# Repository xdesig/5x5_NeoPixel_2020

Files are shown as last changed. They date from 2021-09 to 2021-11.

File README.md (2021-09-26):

# Pantalla 25 (5x5) Neopixel 2020



## Aplicación
Con EchidnaBlack


## Serigrafía
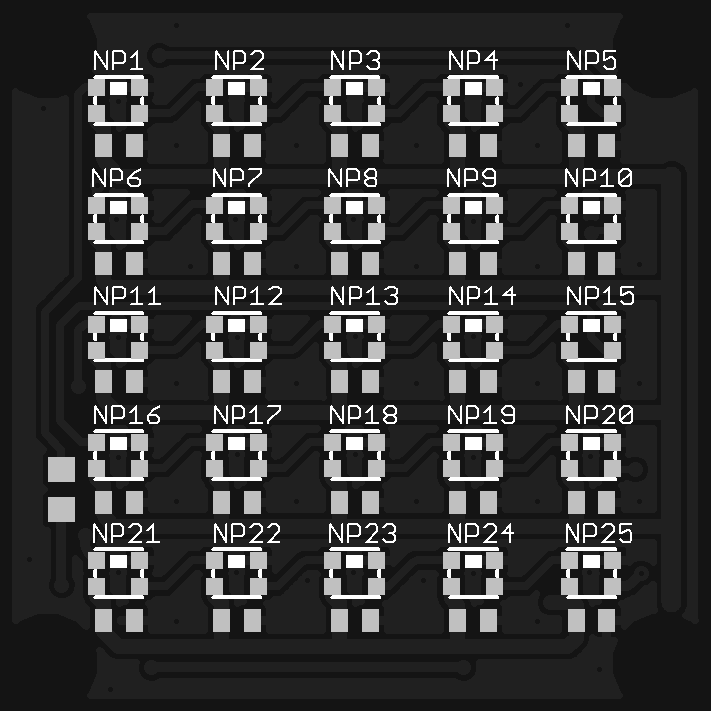
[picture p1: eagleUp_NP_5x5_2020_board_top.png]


## Esquema
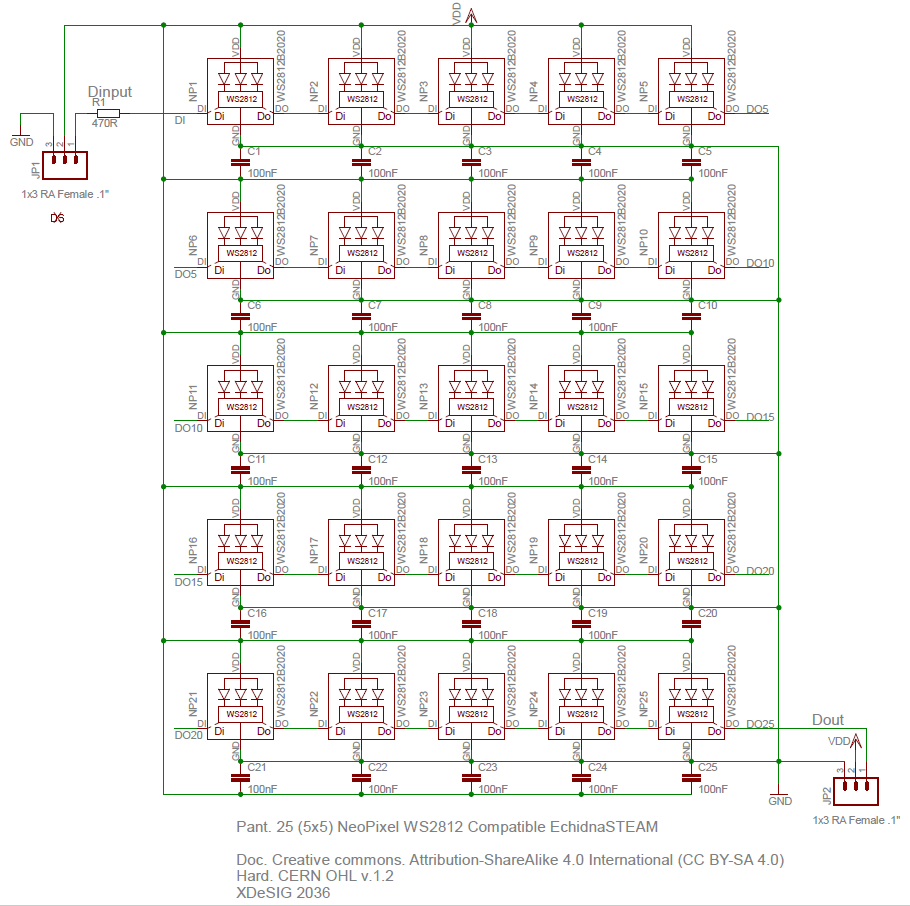
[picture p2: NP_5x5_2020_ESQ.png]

Os capacitores son opcionais

## Licencia
Doc. Creative commons. Attribution-ShareAlike 4.0 International (CC BY-SA 4.0) Hard. CERN OHL v.1.2XDeSIG 2036

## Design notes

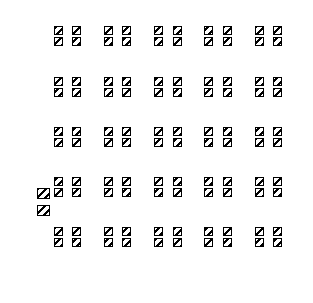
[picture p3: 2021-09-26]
NP_5x5_2020_Stenc_XC.png

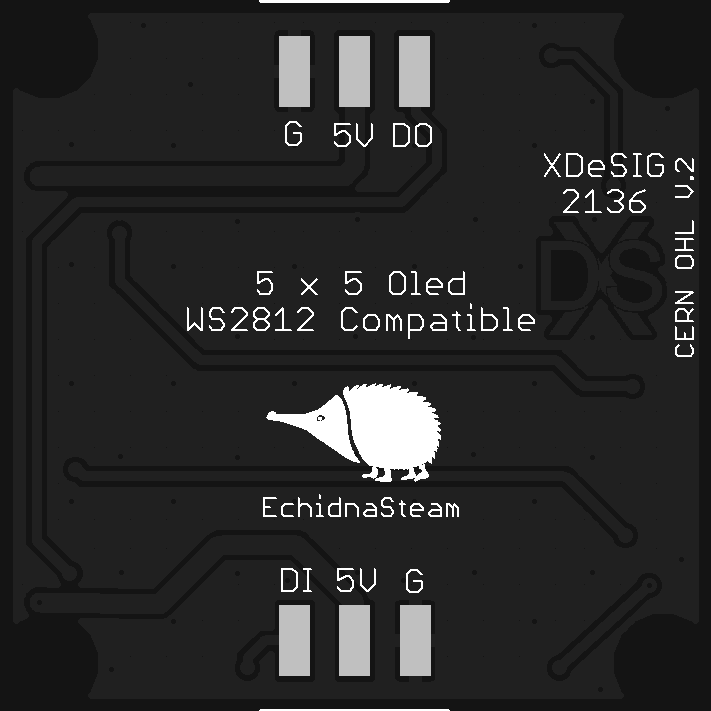
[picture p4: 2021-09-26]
eagleUp_NP_5x5_2020_board_bottom.png

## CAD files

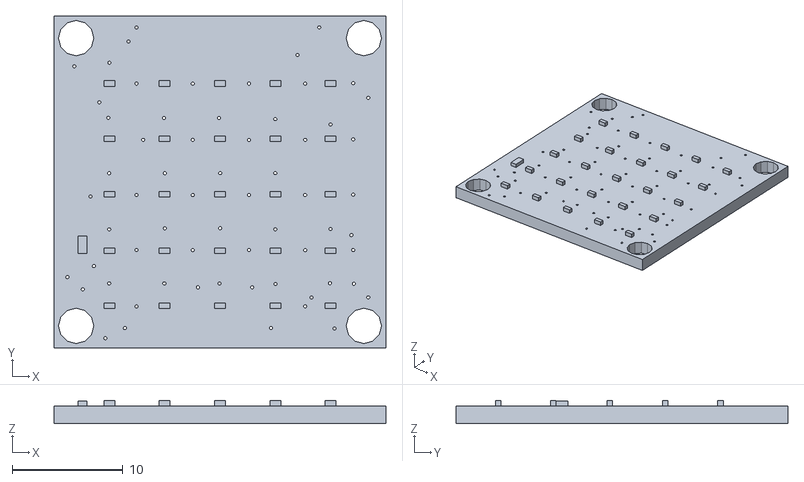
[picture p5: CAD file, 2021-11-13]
3D/NP_5x5_2020.stl
30.0 x 30.0 x 2.10

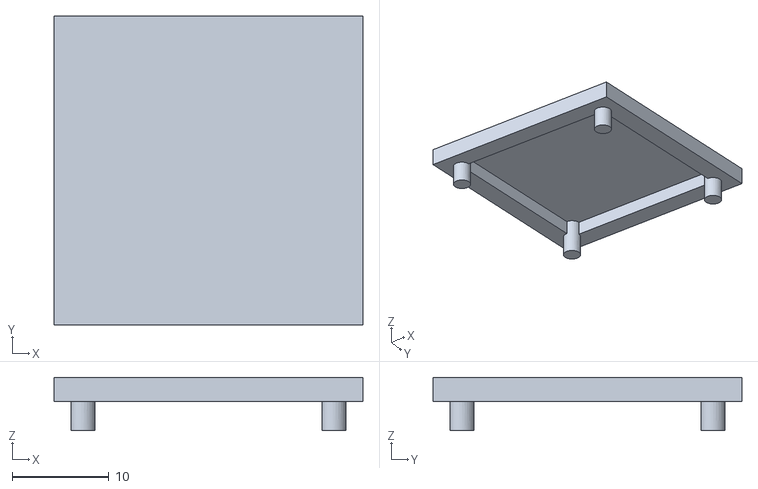
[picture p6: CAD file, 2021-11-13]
3D/NP_5x5_2020_cubre.stl
32.0 x 32.0 x 5.50

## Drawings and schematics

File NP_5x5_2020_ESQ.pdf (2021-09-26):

## Dinput

# XDeSIG 2036 WS²⁸¹²B²⁰²⁰

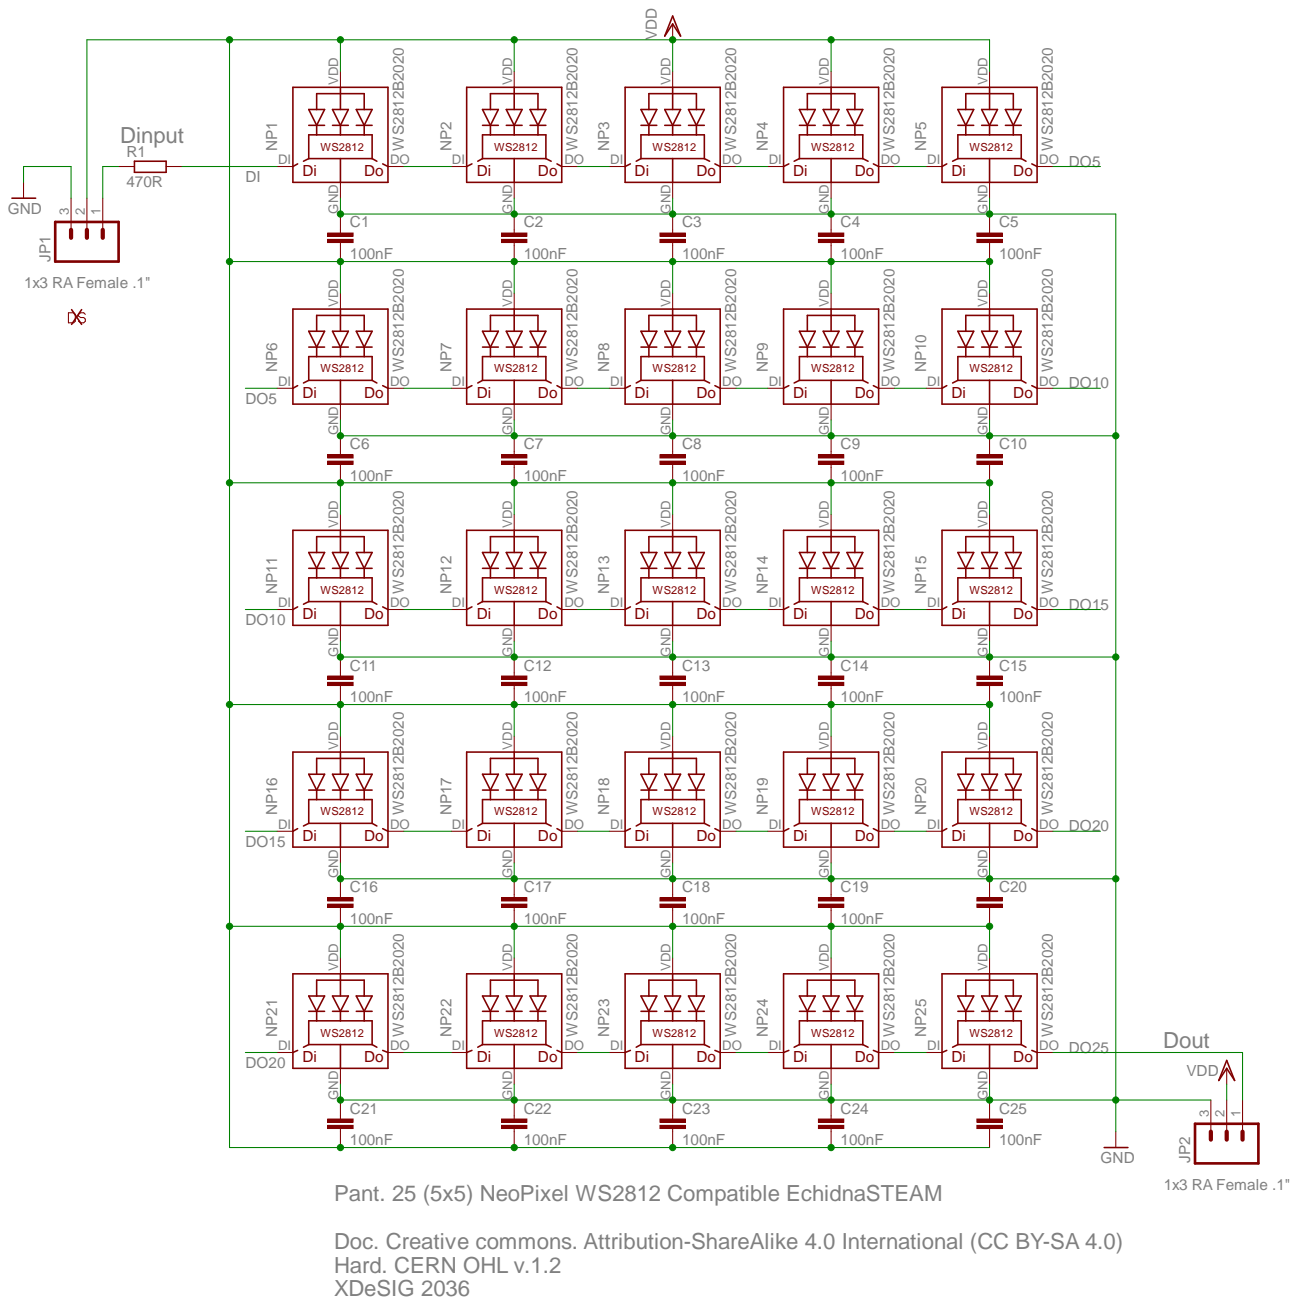
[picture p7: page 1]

Pant. 25 (5x5) NeoPixel WS2812 Compatible EchidnaSTEAM

Doc. Creative commons. Attribution-ShareAlike 4.0 International (CC BY-SA 4.0)
Hard. CERN OHL v.1.2

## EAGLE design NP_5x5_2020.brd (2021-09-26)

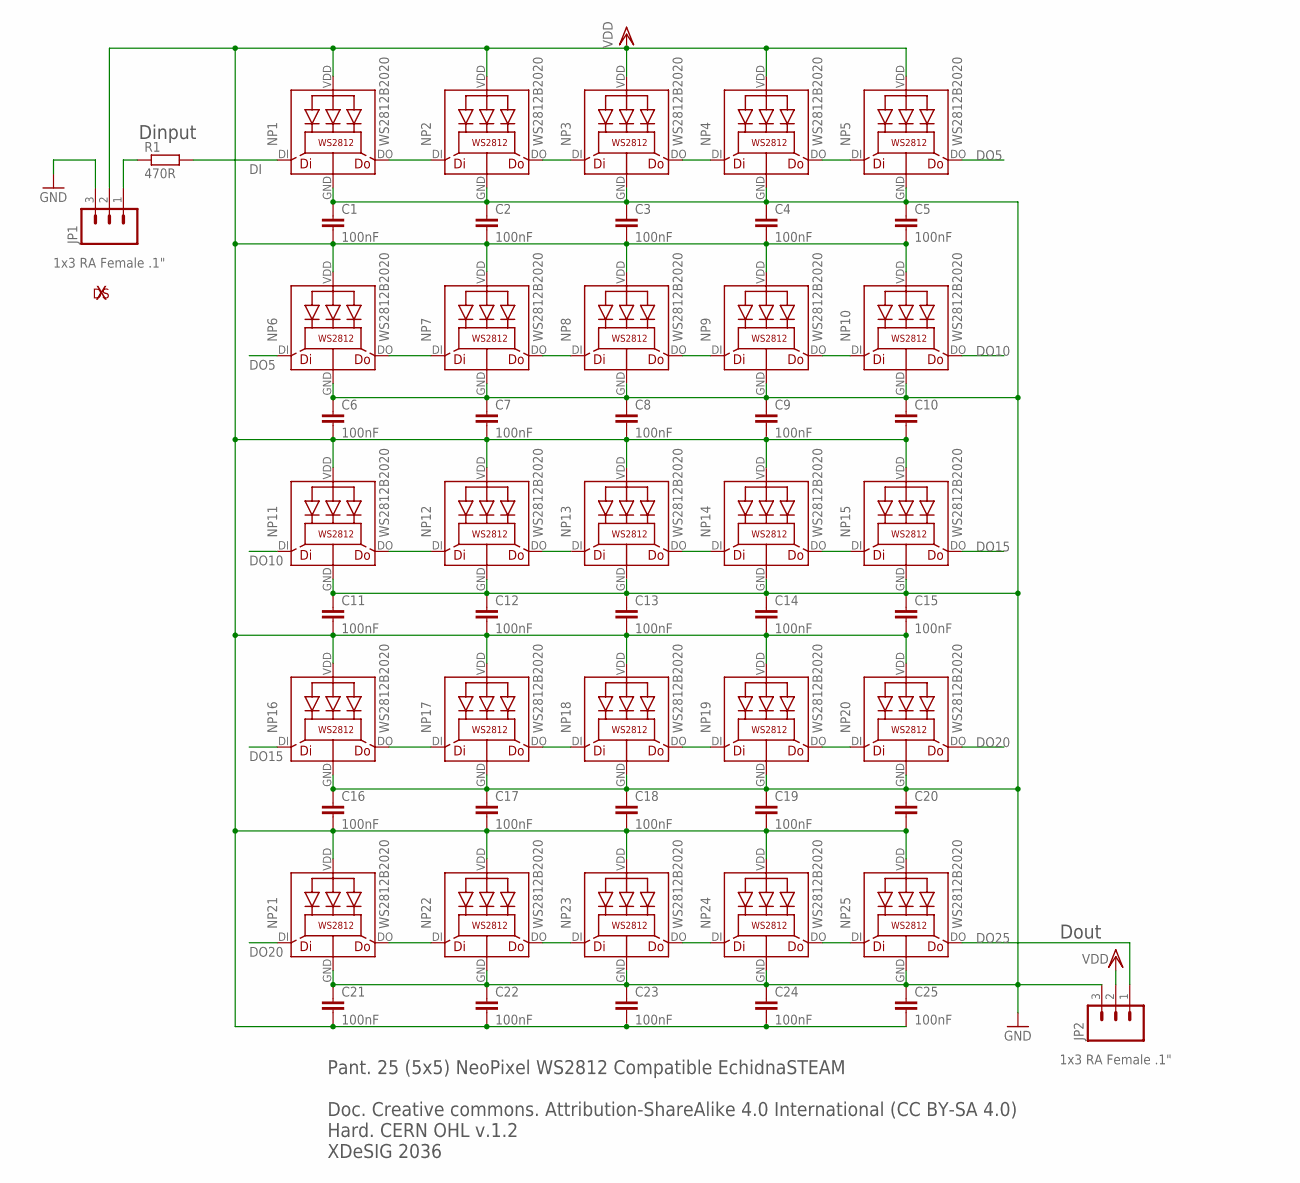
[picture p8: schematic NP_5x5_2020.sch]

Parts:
C1, C2, C3, C4, C5, C6, C7, C8, C9, C11, C12, C13, C14, C15, C16, C17, C18, C19, C21, C22, C23, C24, C25: 100nF; C0402
C10, C20: C-EUC0402; C0402
JP1, JP2: 1x3 RA Female .1"; 1X03_SMD_RA_FEMALE
NP1, NP2, NP3, NP4, NP5, NP6, NP7, NP8, NP9, NP10, NP11, NP12, NP13, NP14, NP15, NP16, NP17, NP18, NP19, NP20, NP21, NP22, NP23, NP24, NP25: WS2812B2020; 2020
R1: 470R; R0603
U$1: XDESIG_XDESIG5MM; XDESIG_XDESIG_CU

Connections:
DI: NP1.DI, R1.2
DO5: NP5.DO, NP6.DI
DO10: NP10.DO, NP11.DI
DO15: NP15.DO, NP16.DI
DO20: NP20.DO, NP21.DI
DO25: JP2.1, NP25.DO
GND: C1.1, C2.1, C3.1, C4.1, C5.1, C6.1, C7.1, C8.1, C9.1, C10.1, C11.1, C12.1, C13.1, C14.1, C15.1, C16.1, C17.1, C18.1, C19.1, C20.1, C21.1, C22.1, C23.1, C24.1, C25.1, JP1.3, JP2.3, NP1.GND, NP2.GND, NP3.GND, NP4.GND, NP5.GND, NP6.GND, NP7.GND, NP8.GND, NP9.GND, NP10.GND, NP11.GND, NP12.GND, NP13.GND, NP14.GND, NP15.GND, NP16.GND, NP17.GND, NP18.GND, NP19.GND, NP20.GND, NP21.GND, NP22.GND, NP23.GND, NP24.GND, NP25.GND
unnamed: NP1.DO, NP2.DI
unnamed: NP2.DO, NP3.DI
unnamed: NP3.DO, NP4.DI
unnamed: NP4.DO, NP5.DI
unnamed: NP22.DO, NP23.DI
unnamed: NP23.DO, NP24.DI
unnamed: NP6.DO, NP7.DI
unnamed: NP7.DO, NP8.DI
unnamed: NP8.DO, NP9.DI
unnamed: NP9.DO, NP10.DI
unnamed: NP11.DO, NP12.DI
unnamed: NP12.DO, NP13.DI
unnamed: NP13.DO, NP14.DI
unnamed: NP14.DO, NP15.DI
unnamed: NP16.DO, NP17.DI
unnamed: NP17.DO, NP18.DI
unnamed: NP18.DO, NP19.DI
unnamed: NP19.DO, NP20.DI
unnamed: NP21.DO, NP22.DI
unnamed: NP24.DO, NP25.DI
unnamed: JP1.1, R1.1
VDD: C1.2, C2.2, C3.2, C4.2, C5.2, C6.2, C7.2, C8.2, C9.2, C10.2, C11.2, C12.2, C13.2, C14.2, C15.2, C16.2, C17.2, C18.2, C19.2, C20.2, C21.2, C22.2, C23.2, C24.2, C25.2, JP1.2, JP2.2, NP1.VDD (LEDVDD), NP2.VDD (LEDVDD), NP3.VDD (LEDVDD), NP4.VDD (LEDVDD), NP5.VDD (LEDVDD), NP6.VDD (LEDVDD), NP7.VDD (LEDVDD), NP8.VDD (LEDVDD), NP9.VDD (LEDVDD), NP10.VDD (LEDVDD), NP11.VDD (LEDVDD), NP12.VDD (LEDVDD), NP13.VDD (LEDVDD), NP14.VDD (LEDVDD), NP15.VDD (LEDVDD), NP16.VDD (LEDVDD), NP17.VDD (LEDVDD), NP18.VDD (LEDVDD), NP19.VDD (LEDVDD), NP20.VDD (LEDVDD), NP21.VDD (LEDVDD), NP22.VDD (LEDVDD), NP23.VDD (LEDVDD), NP24.VDD (LEDVDD), NP25.VDD (LEDVDD)

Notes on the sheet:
Dout
Dinput
Pant. 25 (5x5) NeoPixel WS2812 Compatible EchidnaSTEAM Doc. Creative commons. Attribution-ShareAlike 4.0 International (CC BY-SA 4.0) Hard. CERN OHL v.1.2 XDeSIG 2036

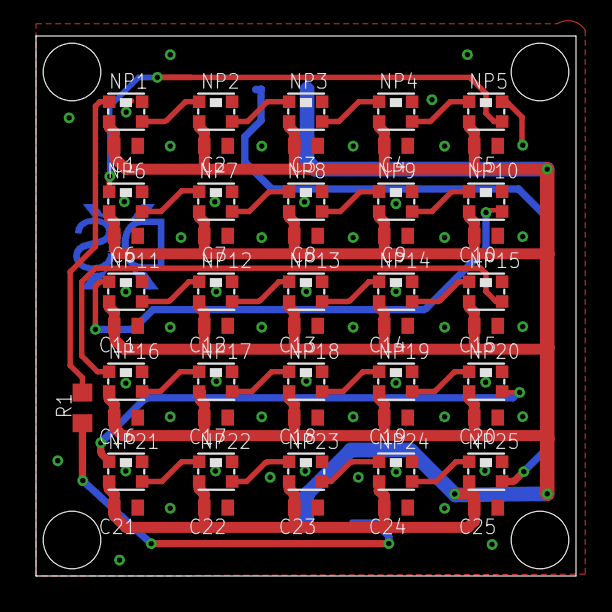
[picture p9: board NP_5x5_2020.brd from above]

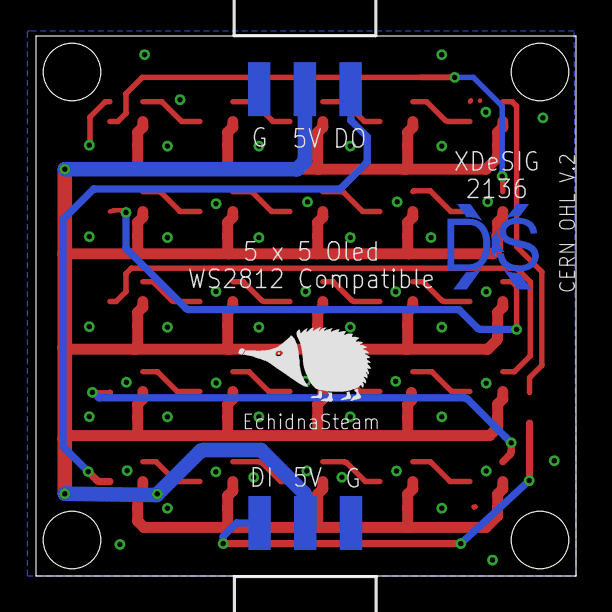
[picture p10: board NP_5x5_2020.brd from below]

Board: 2 copper layers, 30.0 x 30.0 mm, 55 parts (4 on the bottom side), 29 nets.

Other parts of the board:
U$3: ECHIDNA_P

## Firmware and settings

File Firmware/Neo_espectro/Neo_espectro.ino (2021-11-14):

/*
    Visualizador de espectro de audio de cinco bandas
    Usando a pantalla de 25 Neopixeles "https://github.com/xdesig/5x5_NeoPixel_2020"
    Transformada rapida de Fourier (FFT). Autor: Dimitrios P. Bouras, mantenida por Enrique Condes
    Pulsando SR aumentamos a amplificacion, Sl baixamos a amplificacion
    O Led vermello indica maxima amplificación o laranxa media e o verde minima. 
    XDeSIG 2021
*/

#include <Adafruit_NeoPixel.h>
#define PIN_NEO A4
#define NUM_LEDS 25
Adafruit_NeoPixel pixels = Adafruit_NeoPixel(NUM_LEDS, PIN_NEO, NEO_GRB + NEO_KHZ800);


#include <fix_fft.h>          // biblioteca para implementar FFT
char re[128], im[128];        // Matrices de muestras / resultados de la FFT
byte i;                       // indice para almacenar as mostras
int dat;                      // variable da amplitude da frecuencia

int F[5] = {2, 3, 6, 9, 15}; // Frecuencias a mostrar en pantalla *73,8Hz

#define MIC A7
// Entrada de Audio (Microfono)

#define SR 2                  // Pulsador para subir a amplificacion
#define SL 3                  // Pulsador para bajar a amplificacion
#define Red 13                // Led vermello (Amplificación maxima)
#define Orn 12                // Led laranxa (Amplificación media)
#define Gre 11                // Led verde (Amplificación minima)

int amp = 25;                 // Valor inicial de amplificacion


int y;                        // Variable de resultados (eixo Y) mapeados para mostrar na pantalla
int x;                        // variable para recorer o eixo x
int A;                        // Amplitude en leds
int pix;                      // Variable de pixel a mostrar (pix = x + y*5)

int R;                        // Variable da cor vermella
int G;                        // Variable da cor verde
int B;                        // Variable da cor azul



void setup() {
  analogReference(INTERNAL);    // Axustamos a referencia do conversos analoxico/dixital a 1.1Volts
  pinMode(SR, INPUT);           // Definimos o rol de cada pin
  pinMode(SL, INPUT);
  pinMode (Red, OUTPUT);
  pinMode (Orn, OUTPUT);
  pinMode (Gre, OUTPUT);

  pixels.begin();              // Inicializamos os neoPixeles
}

void loop() {

  // *** Comprobamos si se pulsou SR para amplificar ou SR par atenuar
  while (digitalRead (SR)) {
    amp = amp + 1;
    if ( amp >= 50) {
      amp = 50;
      digitalWrite (Red, 1);
      digitalWrite (Orn, 0);
      digitalWrite (Gre, 0);
    }
    delay(100);
  }
  while (digitalRead (SL) ) {
    amp = amp - 1;
    if ( amp <= 1) {
      amp = 1;
      digitalWrite (Red, 0);
      digitalWrite (Orn, 0);
      digitalWrite (Gre, 1);
    }
    delay(100);
  }
  // *** Comprobamos si o valor de amplificacion e medio e acendemos o led laranxa
  if (amp > 20 and amp < 30) {
    digitalWrite (Red, 0);
    digitalWrite (Orn, 1);
    digitalWrite (Gre, 0);
  }



  //*** lectura de audio e conversion a amplitude por frecuencia.

  for (i = 0; i < 128; i++) {                     // Tomamos 128 mostras da entrada analoxica (micro)
    int sample = amp * (analogRead(MIC));
    re[i] = sample / 4 - 128;                     // Escalamos a variable para que se axuste a un caracter de -128 a 127
    im[i] = 0;                                    // Neste momento non temos valores imaxinarios e poñemos todos a cero
  }
  fix_fft(re, im, 7, 0);                          // Enviamos as mostras para a conversión FFT, devolvendo os resultados reais/imaxinarios nas mesmas matrices


  for (x = 0; x < 5; x++) {                       // Recorremos o eixo x da pantalla

    dat = sqrt(re[F[x]] * re[F[x]] + im[F[x]] * im[F[x]]);     // A magnitude da frecuencia é a raíz cadrada da suma dos cadrados das partes real e imaxinaria dos vectores
    // Solo recuperamos os valores das frecuencias elixidas F[x]

    A = map(dat, 0, 25, 4, 0);                                 // Mapeamos os valores de amplitude de cada frecunencia os pixeles verticais

    for (y = 5; y >= A  ; y--) {                               // Comprobamos cantos pixeles verticais acendemos

      pix = x + y * 5;                                         // Pasamos  as coordenadas X e Y a linea de pixeles

      if (y == 0) {                                            // Axustamos a cor a cada liña
        R = 32;
        G = 0;
        B = 0;
      }
      if (y == 1) {
        R = 16;
        G = 8;
        B = 4;
      }
      if (y == 2) {
        R = 16;
        G = 8;
        B = 16;
      }

      if (y == 3) {
        R = 4;
        G = 0;
        B = 16;
      }
      if (y == 4) {
        R = 0;
        G = 2;
        B = 2;
      }
      pixels.setPixelColor(pix, pixels.Color(R, G, B));           // Acendemos cada pixel ca sua cor
    }
    for (int y = 0; y < A  ; y++) {                               // Comprobamos que pixeles apagar
      pix = x + y * 5 ;
      pixels.setPixelColor(pix, pixels.Color(0, 0, 0));           // Apagamos cada pixel selecionado
    }
    pixels.show();                                                // Enviamos os datos a pantalla de NeoPixeles
  }
}

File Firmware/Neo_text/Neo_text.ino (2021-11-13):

#include <Adafruit_NeoPixel.h>
#ifdef __AVR__
#include <avr/power.h>
#endif
#define PIN A4
#define NUM_LEDS 25

boolean E[25] = {0, 1, 1, 1, 1,  0, 1, 0, 0, 0,  0, 1, 1, 1, 0,  0, 1, 0, 0, 0,  0, 1, 1, 1, 1};
boolean C[25] = {0, 0, 1, 1, 1,  0, 1, 0, 0, 0,  0, 1, 0, 0, 0,  0, 1, 0, 0, 0,  0, 0, 1, 1, 1};
boolean H[25] = {0, 1, 0, 0, 1,  0, 1, 0, 0, 1,  0, 1, 1, 1, 1,  0, 1, 0, 0, 1,  0, 1, 0, 0, 1};
boolean I[25] = {0, 1, 1, 1, 0,  0, 0, 1, 0, 0,  0, 0, 1, 0, 0,  0, 0, 1, 0, 0,  0, 1, 1, 1, 0};
boolean D[25] = {0, 1, 1, 0, 0,  0, 1, 0, 1, 0,  0, 1, 0, 0, 1,  0, 1, 0, 1, 0,  0, 1, 1, 0, 0};
boolean N[25] = {0, 1, 0, 0, 1,  0, 1, 1, 0, 1,  0, 1, 0, 1, 1,  0, 1, 0, 0, 1,  0, 1, 0, 0, 1};
boolean A[25] = {0, 0, 1, 0, 0,  0, 1, 0, 1, 0,  0, 1, 0, 0, 1,  0, 1, 1, 1, 1,  0, 1, 0, 0, 1};
int wait = 200;
int ret1 = 100;
int R;
int G;
int B;
int i = 0;
Adafruit_NeoPixel pixels = Adafruit_NeoPixel(NUM_LEDS, PIN, NEO_GRB + NEO_KHZ800);

void setup() {
  for (int j = 0; j < 10; j++) {
    pixels.begin();

    for (i = 0; i < 25; i++) {
      R = random(0, 32); G = random(0, 32); B = random(0, 32);
      pixels.setPixelColor(i, pixels.Color(R, G, B));
      pixels.show();
      delay(ret1);
    }
  }
  
  for (i = 0; i < NUM_LEDS; i++) {
    pixels.setPixelColor(i, pixels.Color(0, 0, 0));
    pixels.show();
    delay(ret1);
  }

  delay(2 * wait);
  R = 8; G = 0; B = 0;
  vis_E(); delay(wait); vis_C(); delay(wait); vis_H(); delay(wait); vis_I(); delay(wait); vis_D(); delay(wait); vis_N(); delay(wait); vis_A();
  delay(wait);
  R = 0; G = 8; B = 0;
  vis_E(); delay(wait); vis_C(); delay(wait); vis_H(); delay(wait); vis_I(); delay(wait); vis_D(); delay(wait); vis_N(); delay(wait); vis_A();
  delay(wait);
  R = 0; G = 0; B = 16;
  vis_E(); delay(wait); vis_C(); delay(wait); vis_H(); delay(wait); vis_I(); delay(wait); vis_D(); delay(wait); vis_N(); delay(wait); vis_A();
  delay(wait);
}
void loop() {

  delay(2 * wait);
  R = random(0, 32); G = random(0, 32); B = random(0, 32);
  vis_E(); delay(wait); vis_C(); delay(wait); vis_H(); delay(wait); vis_I(); delay(wait); vis_D(); delay(wait); vis_N(); delay(wait); vis_A();
}


void vis_E() {
  for (i = 0; i < NUM_LEDS; i++) {
    pixels.setPixelColor(i, pixels.Color(R * E[i], G * E[i], B * E[i])); //
    pixels.show();
  }
}
void vis_C() {
  for (i = 0; i < NUM_LEDS; i++) {
    pixels.setPixelColor(i, pixels.Color(R * C[i], G * C[i], B * C[i])); //
    pixels.show();
  }
}
void vis_H() {
  for (i = 0; i < NUM_LEDS; i++) {
    pixels.setPixelColor(i, pixels.Color(R * H[i], G * H[i], B * H[i])); //
    pixels.show();
  }
}

void vis_I() {
  for (i = 0; i < NUM_LEDS; i++) {
    pixels.setPixelColor(i, pixels.Color(R * I[i], G * I[i], B * I[i])); //
    pixels.show();
  }
}
void vis_D() {
  for (i = 0; i < NUM_LEDS; i++) {
    pixels.setPixelColor(i, pixels.Color(R * D[i], G * D[i], B * D[i])); //
    pixels.show();
  }
}

void vis_N() {
  for (i = 0; i < NUM_LEDS; i++) {
    pixels.setPixelColor(i, pixels.Color(R * N[i], G * N[i], B * N[i])); //
    pixels.show();
  }
}

void vis_A() {
  for (i = 0; i < NUM_LEDS; i++) {
    pixels.setPixelColor(i, pixels.Color(R * A[i], G * A[i], B * A[i])); //
    pixels.show();
  }
}

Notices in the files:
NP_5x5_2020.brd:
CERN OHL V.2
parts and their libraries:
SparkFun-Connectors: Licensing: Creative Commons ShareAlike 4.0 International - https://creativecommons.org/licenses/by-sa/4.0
